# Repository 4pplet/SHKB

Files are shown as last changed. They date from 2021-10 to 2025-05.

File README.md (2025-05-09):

# SHKB
A alternative controller for the HHKB pro 2 with integrated hub. The full-version features a SuperSpeed 5.0 Gbps USB 3.1 Hub, the lite-version features a USB 2.0 MTT hub. The lite-version is available in USB-mini as a drop in replacement for the OG controller. For the full version to fit in a HHKB Pro 2 plastic case, the opening for the USB-port needs slight modification for the USB-C port.

Thread on GH: https://geekhack.org/index.php?topic=93970.0

## Availability:
As an option to DIY, I'll try and keep these available for purchase here: https://4pplet.com/ For DIY, the production files are avaliable in releases.

## Status - Full (USB3.1):
- Prototype round 2 of Rev A. PCB produced and delivered to testers, currently 5 PCB's being used, two HHKB JP, three regular ANSI. So far working great.
- 2021-03-16: New proto-run being made with some changed components better suited for manufacturing and connectors that better fits custom projects.
- 2021-06-29: New proto-run being made with fixed issues on the USB-A connectors introduced in revision B1. Minor trace-tweaks and a new inductor for the 1.1v regulator.
- Small production run planned sometime in the beginning of next year
- 2024-06-20: New revision B4 with minor adjustments ordered and tested. Adds support for LQFP Atmega and adds write protect for EEPROM in default state.

## Status - Lite (USB 2.0):
- 2022-03-16: Initial prototype round ordered for mini-version. Tested and one bug found. 
- 2022-04-10: Issue in A1 have been fixed and A2 files have been released. Patch done in A2 have been tested on A1 prototypes.
- 2025-05-09: Adds support for a USB-C riser PCB.

## Features - Full (USB3.1):
- 3 available USB3 ports, two external, one internal. Hub: TUSB8042A
- ATMEGA32U4 for keyboard firmware (TMK/QMK/VIA), uses current implementations for HHKB
- 900mA per port current limit on each downstream port using TPS2552D
- Will require modification of hhkb case because of the usb-c connector

## Features - Lite (USB 2.0):
- 2 external USB2 ports. HUB: FE1.1
- ATMEGA32U4 for keyboard firmware (TMK/QMK/VIA), uses current implementations for HHKB
- Per port current limit on each downstream port using MIC2026-2
- Drop-in replacement for the OG controller

## Future work - Lite (USB2.0)
- Improve and release USB-C Riser PCB.

## PCB - Full
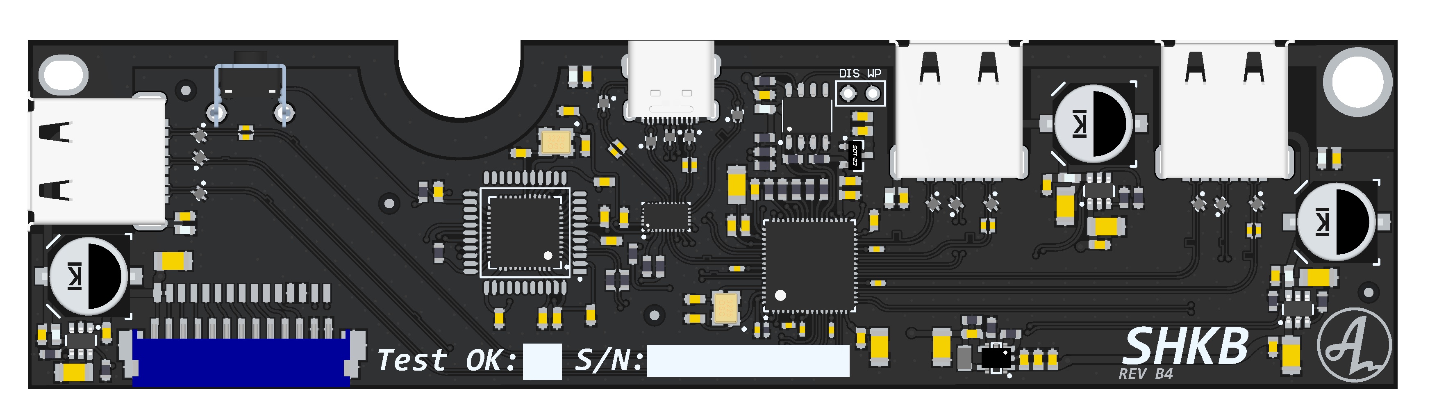
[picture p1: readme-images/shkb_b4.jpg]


## PCB - Lite
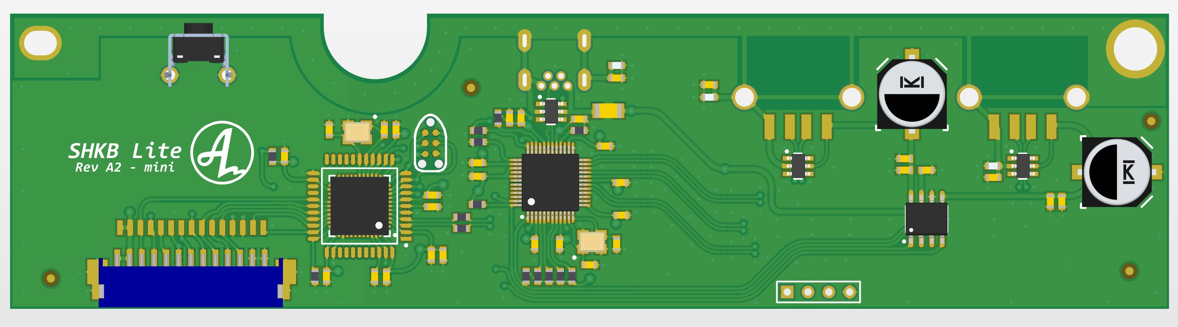
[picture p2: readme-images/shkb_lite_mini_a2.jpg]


## Build guide SHKB Full

The PCB is designed to use this build up:
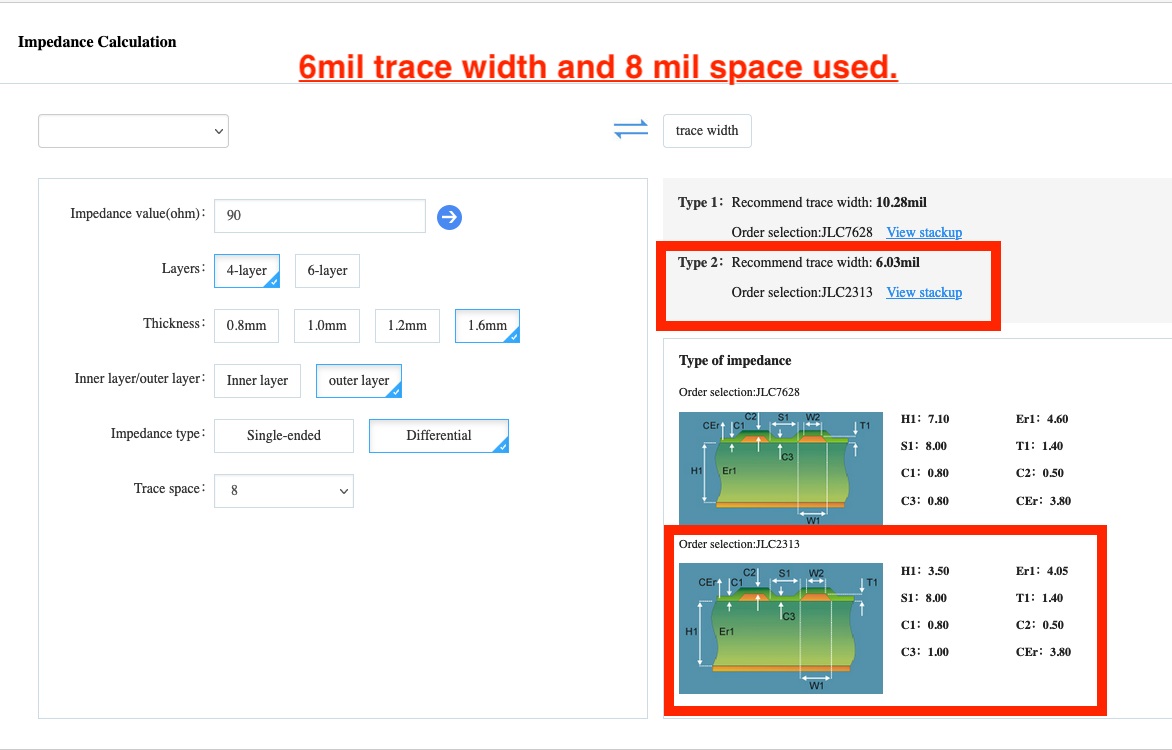
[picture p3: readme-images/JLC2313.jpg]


The PCB is designed with some specific specs in mind:
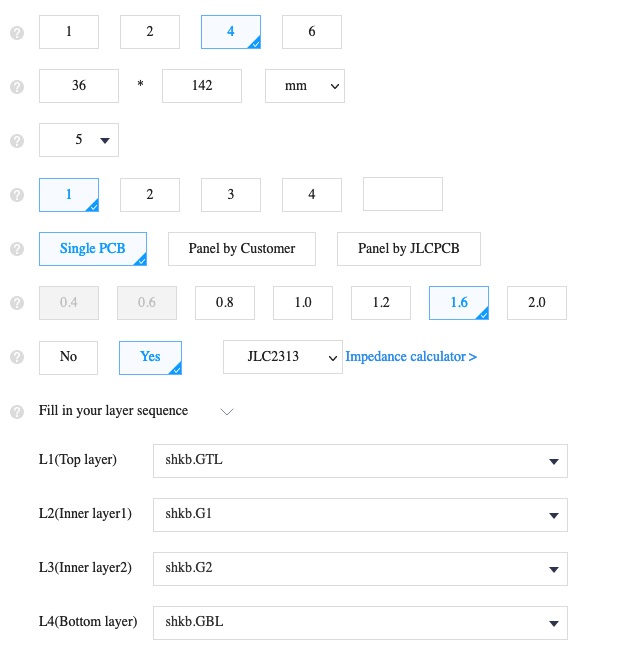
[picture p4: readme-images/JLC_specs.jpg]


When placing an order, you'll need to specify the layer stackup, enter the layers in this order:
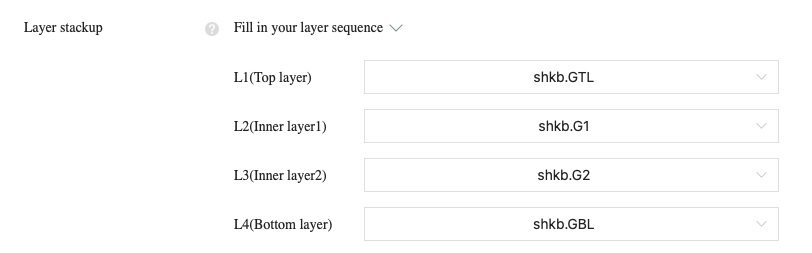
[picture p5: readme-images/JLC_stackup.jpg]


Case modification needed for the full version:
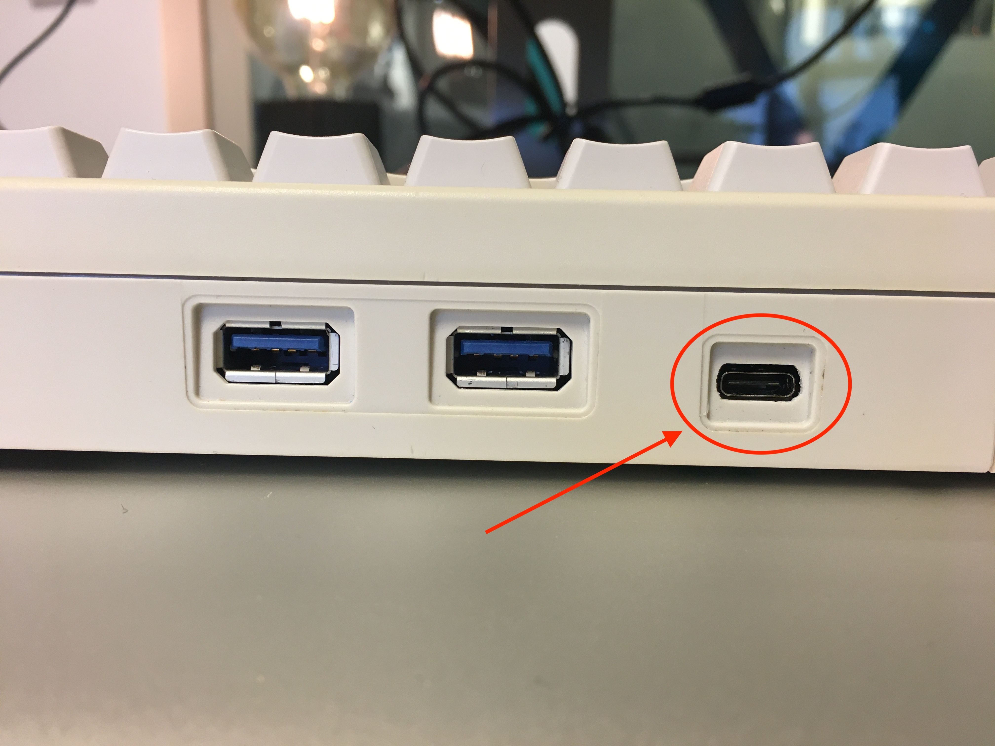
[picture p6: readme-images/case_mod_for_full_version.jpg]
MOD


### Update 2023-05-02.
JLC are no longer offering the JLC2313 substrate. The closest according to their own calcullator seems to be the JLC04161H-2313 so I'd recommend trying that for JLC orders.

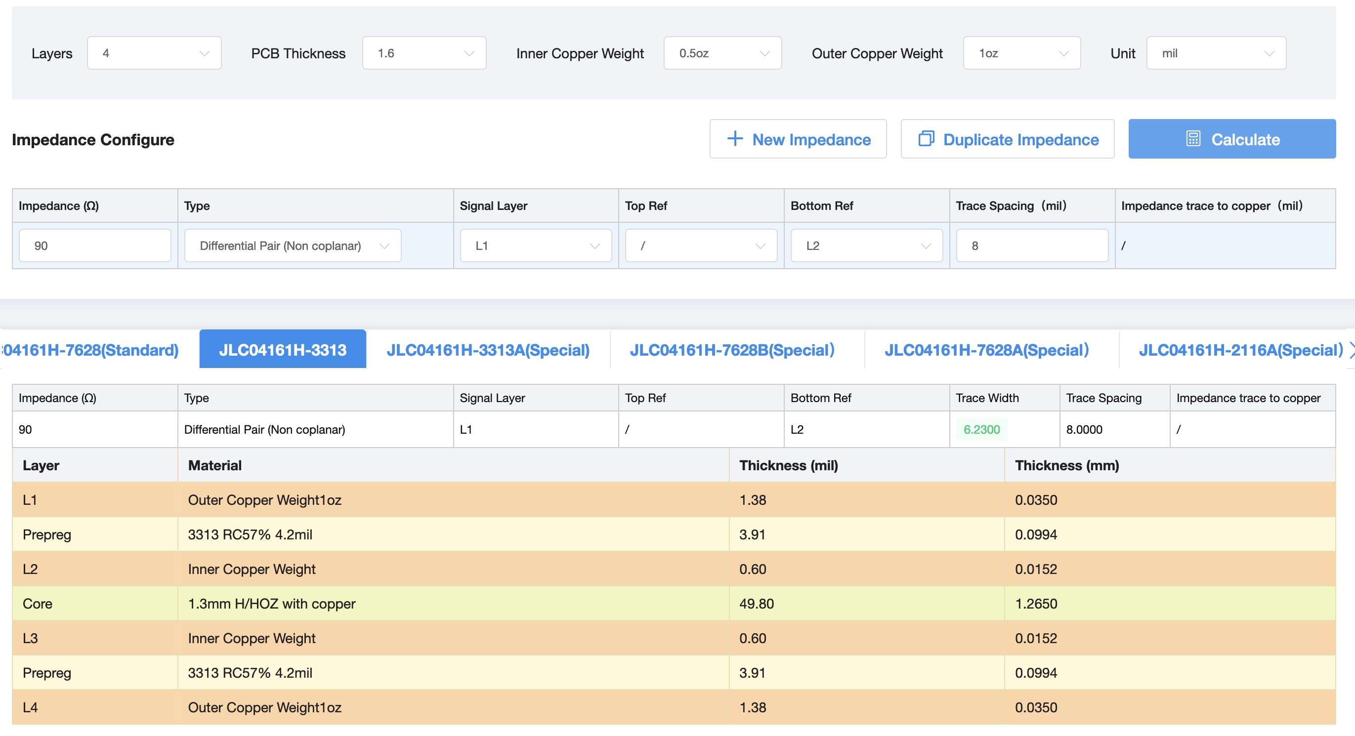
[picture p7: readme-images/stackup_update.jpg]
JLC04161H-2313


When having the SHKB Full PCBs produced, you'll also need to flash the on board EEPROM. This EEPROM contains the configuration for the USB-Hub. I have prepared a config that works well in the EEPROM config folder in this repo. This can be flashed either using a external programmer or use the "TUSB80xx_EEPROM_Programmer". I am not allowed to share this software, but you can usually get access to it if you ask the Texas Instruments support or ask in their forum. The config provided as a .txt can be directly loaded into the TI software and the EEPROM can be flashed without the use of a external programmer. Revision B4 adds a header above the EEPROM that need to be shorted during programming, to disable write protection of the EEPROM. I usually just put a pair of pliers into the header during flashing.

<a href='https://ko-fi.com/4pplet' target='_blank'>Buy Me a Coffee at ko-fi.com

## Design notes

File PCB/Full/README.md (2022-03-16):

# SHKB
A alternative controller for the HHKB pro 2 with integrated hub. The full-version features a SuperSpeed 5.0 Gbps USB 3.1 Hub, the lite-version features a USB 2.0 MTT hub. The lite-version is available in both USB-mini and USB-C. SHKB lite mini is a drop in replacement for the original PCB, the c-version will need modification of the Pro 2 case in the same way as the full-version.

## Status - full:
- Prototype round 2 of Rev A. PCB produced and delivered to testers, currently 5 PCB's being used, two HHKB JP, three regular ANSI. So far working great.
- 2021-03-16: New proto-run being made with some changed components better suited for manufacturing and connectors that better fits custom projects.
- 2021-06-29: New proto-run being made with fixed issues on the USB-A connectors introduced in revision B1. Minor trace-tweaks and a new inductor for the 1.1v regulator.

## **Note - full:**
- Rev A is tested and works properly.
- **Rev B is a work in progress. Base functionality is tested. Need to do long term testing and verify USB 3.0 speeds and reliability.**

## Features:
- 3 available USB3 ports, two external, one internal. Hub: TUSB8042A
- ATMEGA32U4 for keyboard firmware (TMK/QMK/VIA), uses current implementations for HHKB
- 900mA per port current limit on each downstream port using TPS2552D
- Will require modification of hhkb case because of the usb-c connector

## PCB
Altium 3D

Thread on GH: https://geekhack.org/index.php?topic=93970.0

## Future work
- Test and verify revision B3.
- Add build guide and flash instructions

<a href='https://ko-fi.com/4pplet' target='_blank'>Buy Me a Coffee at ko-fi.com

## Status - Lite:
- 2022-03-16: Initial prototype round ordered for mini-version. Files for protos is added as pre-release. Untested.

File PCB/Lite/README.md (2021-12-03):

# SHKB
A alternative controller for the HHKB with integrated SuperSpeed 5.0 Gbps USB 3.1 Hub.

## Status:
- Prototype round 2 of Rev A. PCB produced and delivered to testers, currently 5 PCB's being used, two HHKB JP, three regular ANSI. So far working great.
- 2021-03-16: New proto-run being made with some changed components better suited for manufacturing and connectors that better fits custom projects.
- 2021-06-29: New proto-run being made with fixed issues on the USB-A connectors introduced in revision B1. Minor trace-tweaks and a new inductor for the 1.1v regulator.

## **Note:**
- Rev A is tested and works properly.
- **Rev B is a work in progress. Currently waiting for protos.**

## Some features:
- 3 available USB3 ports, two external, one internal. Hub: TUSB8042A
- ATMEGA32U4 for keyboard firmware (TMK/QMK/VIA), uses current implementations for HHKB
- 900mA per port current limit on each downstream port using TPS2552D
- Will require modification of hhkb case because of the usb-c connector

## Altium view of PCB
Altium 3D

Thread on GH: https://geekhack.org/index.php?topic=93970.0

## Future work
- Test and verify revision B3.

<a href='https://ko-fi.com/4pplet' target='_blank'>Buy Me a Coffee at ko-fi.com

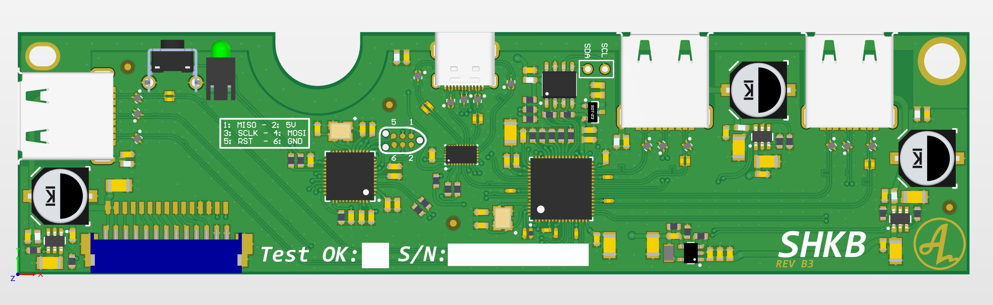
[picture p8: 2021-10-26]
readme-images/shkb_b3.jpg

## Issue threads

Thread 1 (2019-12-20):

USB-C without case modification

edwardxia, 2019-12-20:
Thanks for the great work.

Apparently, there’s a cleaver way to fit the USB-C port in the existing cut of mini-USB: https://github.com/manisteinn/usb-type-c-hhkb

Hasu is making a similar implementation available: https://geekhack.org/index.php?topic=103495.0

> Type-C connector is implemented on castellated daughter pcb to tune its height to the existent opening.

Would you consider it in the next iteration?

4pplet, 2019-12-20:
Thanks for showing interest in the project!

Yes, I have seen that solution and I agree, it is clever and really nice that there is no need to modify the case.

While that is a neat solution, I do not think it will work on this board, this due to the very tight tolerances for USB3 traces. In the hasu controller, they run regular USB2.0, where signal impedance matching etc is a lot less critical.

Preferably, I'd like to find a USB-C connector for USB3 that sit a bit higher than my current one, so that there is no need to modify the case, but I have yet to find one that is suitable.

Cheers!

edwardxia, 2019-12-20:
https://www.mouser.com/datasheet/2/206/J119851-1499861.pdf

https://www.mouser.com/datasheet/2/222/KUSBX-SMTTH-CSE-1621703.pdf

I’m not familiar with hardware at all, but any chance one of these kinds may work?

4pplet, 2019-12-20:
I think the connector you linked will end up a bit too high, and thus will need modification anyway, I'll look in to it closer.

The connector will work considering the other aspects I think (PCB thickness etc), tho it will be a bit more of a pain to solder, since it has SMD-pads that is hidden by the connector.

Closed 2020-04-28.

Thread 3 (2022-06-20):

for hhkb bt

3000ye, 2022-06-20:
你好，请问可以添加对hhkb bt 的支持嘛。
我手上只有bt版的，无法烧录固件。

4pplet, 2024-06-27:
Apologies for the late response. This project will only be for the HHKB Pro 2. There is work on getting the newer HHKBs to run QMK, since they have hardware capable of doing so. I believe this should also be valid for the HHKB BT.

https://geekhack.org/index.php?topic=106213.0

Closed 2024-06-27.

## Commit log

2017-06-16 initial commit, test run of alpha test
    [0_project_description.SchDoc, 1_top_sheet.SchDoc, 2_hub.SchDoc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]
2017-06-16 fixed unplated hols for USB3-connector
    [lib.PcbLib]
2017-07-12 started implementing USB-C mux
    [1_top_sheet.SchDoc, 2_hub.SchDoc, 6_upstream_con.SchDoc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]
2019-03-22 Bunch of changes, fixed error in SS data lines, RX was connected to TX downstream. Moved all components to component side. Moved internal layers on PCB stackup. Major commit.
    [1_top_sheet.SchDoc, 2_hub.SchDoc, 3_downstream_con.SchDoc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]
2019-04-08 Files used for prototype run
    [0_project_description.SchDoc, 1_top_sheet.SchDoc, 2_hub.SchDoc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]
2019-08-26 files for second prototype round
    files for second prototype round
    [1_top_sheet.SchDoc, 2_hub.SchDoc, 3_downstream_con.SchDoc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]
2019-09-05 Minor clean up in schematic and adjusting pours
    Minor clean up in schematic and adjusting pours. Added fiducials
    [2_hub.SchDoc, 4_downstream_power.SchDoc, 6_upstream_con.SchDoc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]
2019-10-07 fixed feducials, moved ICSP-header to component layer
    fixed feducials, moved ICSP-header to component layer
    [HHKB_3_0.PrjPcb]
2019-10-13 Removed two inductors left from prototyping stage
    Removed two inductors left from prototyping stage
    [5_power_supply.SchDoc, HHKB_3_0.PrjPcb]
2019-10-31 Files should be ready for rev A3
    Files should be ready for rev A3
    [2_hub.SchDoc, HHKB_3_0.PrjPcb, lib.PcbLib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]
2019-11-03 minor adjustments
    minor adjustments
    [2_hub.SchDoc]
2019-11-03 Added a few gnd vias around traces at upstream-connector
    Added a few gnd vias around traces at upstream-connector
2019-11-05 updated silk, tweaked component placement.
    updated silk, tweaked component placement. Still need to tweak USB connector placement (measurements from A1 proto)
    [7_kbd.SchDoc]
2019-11-05 Started moving connectors
    Started moving connectors
    [7_kbd.SchDoc]
2019-11-08 should only be lengthmatching left. Updated out-file
    should only be lengthmatching left. Updated out-file
    [7_kbd.SchDoc]
2019-11-08 changed atmega crystal load cap to 18pF, same as hub
    changed atmega crystal load cap to 18pF, same as hub
    [7_kbd.SchDoc]
2019-11-09 done length matching, Rev A2 should be done, just need final check up
    done length matching, Rev A2 should be done, just need final check up
    [7_kbd.SchDoc]
2019-11-09 changed atmega usb resistors to 0603 from 0402
    changed atmega usb resistors to 0603 from 0402
    [2_hub.SchDoc, 3_downstream_con.SchDoc, 4_downstream_power.SchDoc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]
2019-11-09 updated footprint in schematic not only pcb
    updated footprint in schematic not only pcb
    [7_kbd.SchDoc]
2019-11-10 changed C210 and C215 to 0602 from 0402 and moved stuff around a bit
    changed C210 and C215 to 0602 from 0402 and moved stuff around a bit
    [2_hub.SchDoc, 5_power_supply.SchDoc, 7_kbd.SchDoc]
2019-11-21 moved con301 0.25mm left, started to redo the length-matching
    moved con301 0.25mm left, started to redo the length-matching. Improved HHKB-main board connector for easier hand soldering of JP connector.
    [7_kbd.SchDoc, lib.PcbLib]
2019-11-23 Done length tuning with recommendations in IBMC4, still need GND vias
    Done length tuning with recommendations in IBMC4, still need GND vias
    [HHKB_3_0.PrjPcb]
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2019-11-26 Added tool for configuring hub (if not programming memory directly)
    Added tool for configuring hub (if not programming memory directly)
    [EEPROM config explanation.Txt]
2019-11-30 Minor tweaks
    Minor tweaks
    [HHKB_3_0.PrjPcb]
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2020-03-17 fixed schematic issue with missing port-names
    fixed schematic issue with missing port-names
2020-07-11 added step output in outfile
    [HHKB_3_0.PrjPcb]
2020-11-23 updated to 0.3 holes for MCU, hub and mux
    [lib.PcbLib]
2020-11-24 minor tweaks
    [7_kbd.SchDoc]
2020-11-24 flipped indicator led and set D603 as no-bom
    [6_upstream_con.SchDoc, 7_kbd.SchDoc]
2020-11-24 fixed fiducials
    [lib.PcbLib]
2020-11-26 corrected partnr for R704 and R705
    [7_kbd.SchDoc]
2020-12-04 cont, DRC OK
    [HHKB_3_0.PrjPcb]
2020-12-05 updated one SS-trace for better length-matching. DRC ok.
    Todo: fix gnd vias for usb-traces. Wait for usb-port aligntment check.
2020-12-07 added a few gnd vias
    [HHKB_3_0.PrjPcb]
2020-12-07 added missing diodes
    [6_upstream_con.SchDoc]
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2020-12-31 rename files in project
    [1_shkb_top.SchDoc, 1_top_sheet.SchDoc, 2_hub.SchDoc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]
2021-01-09 cleaning up schematics
    [1_shkb_top.SchDoc, 2_shkb_hub.SchDoc, 3_shkb_downstream_con.SchDoc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]
2021-01-09 updating schematic info
    [1_shkb_top.SchDoc, 2_shkb_hub.SchDoc, 3_shkb_downstream_con.SchDoc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]
2021-01-10 cleaning up schematic
    [6_shkb_upstream_con.SchDoc]
2021-01-18 bumping revision number
    [3_shkb_downstream_con.SchDoc, shkb.PrjPcb]
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2021-04-23 fixed incorrect PN on R206
    [2_shkb_hub.SchDoc]
2021-04-23 simplifying cap values in BOM a bit.
    [4_shkb_downstream_power.SchDoc, 5_shkb_power_supply.SchDoc]
2021-04-30 updated port controllers. Reverting back to TI-controller.
    [2_shkb_hub.SchDoc, 4_shkb_downstream_power.SchDoc]
2021-06-24 minor tweaks, still need to do length matching etc. Added header for I2C for programming eeprom without TI-software
    minor tweaks, still need to do length matching etc. Added header for I2C for programming eeprom without TI-software
    [2_shkb_hub.SchDoc]
2021-06-24 rotated two EDS-chips, changed inductor for 1.1v to a more easily available (at JLC)
    rotated two EDS-chips, changed inductor for 1.1v to a more easily available (at JLC). Updated outjob
    [2_shkb_hub.SchDoc, 5_shkb_power_supply.SchDoc, 6_shkb_upstream_con.SchDoc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]
2021-10-25 updating to rev B3, issues found in B2.
    [1_shkb_top.SchDoc, 2_shkb_hub.SchDoc, 5_shkb_power_supply.SchDoc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]
2021-10-26 update esd chip PN
    [3_shkb_downstream_con.SchDoc, 6_shkb_upstream_con.SchDoc, shkb.PrjPcb]
2022-04-10 Squashed commit of the following:
    commit 98e93ed0b47356e8e52355aa3e1896254b8b05c0
    Author: 4pplet <mail@4pplet.com>
    Date: Sun Apr 10 10:31:49 2022 +0200
    DRC double checked, ready for release on main
    commit 725b8519ce5f88cd91393378b17d91e68e10590b
    Author: 4pplet <mail@4pplet.com>
    Date: Thu Apr 7 21:46:32 2022 +0200
    Update shkb_lite_c.PcbDoc
    commit d62cf72e833862d78c7f4bba57f36dc24c75d3d5
    Author: 4pplet <mail@4pplet.com>
    Date: Thu Apr 7 08:49:04 2022 +0200
    cont
    commit b692b7650d26416a92e9165455937015b8887c1c
    Author: 4pplet <mail@4pplet.com>
    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
    [1_shkb_lite_mini_top.SchDoc, 1_shkb_top.SchDoc, 2_shkb_hub.SchDoc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]
2024-02-04 Rev B4 done for prototyping
    [2_shkb_hub.SchDoc, 3_shkb_downstream_con.SchDoc, 4_shkb_downstream_power.SchDoc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]
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2024-10-25 adding riser-support for USB-C
    adding riser-support for USB-C
    [1_shkb_lite_mini_top.SchDoc, 1_shkb_lite_top.SchDoc, 2_shkb_lite_hub.SchDoc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]
2024-10-25 renaming folder
    [1_shkb_lite_top.SchDoc, 2_shkb_lite_hub.SchDoc, 3_shkb_lite_kbd.SchDoc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]
